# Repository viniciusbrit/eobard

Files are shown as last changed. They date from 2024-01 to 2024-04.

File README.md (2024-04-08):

# Meet Eobard, a split 34 key ortholinear keyboard.
Current Hardware Revision: 0.2.8



## Project Description
Eobard is an ortholinear 34 key split keyboard made for my personal needs. Inspired by the [Ferris](https://github.com/pierrechevalier83/ferris).

The columns are spaced out vertically so as to provide the most comfortable typing experience for my hand size. It is designed to be cheap to manufacture and simple to assemble. The single PCB is dual sided, only having to be flipped around for assembly of the other side.

<details>
<summary>Hardware Tasks</summary>

- [x] Design Layout. 
- [x] Design PCB & Plate.
- [x] Generate Gerbers.
- [x] Build Prototype.
- [ ] Write Build Guide with images.
- [x] Change 5th Column Spacing to a more comfortable distance.
- [ ] Make the right side's BOOTSEL button more accessible after soldering.
- [x] Get permission to use the BTW creature in silkscreen.
- [x] Change Placement of TRRS footprints on PCB.
- [x] Move Thumb Keys to Rows 4 and 5.
- [x] Make board diodeless.
- [ ] Release First Version.
</details>

<details>
<summary>Software Tasks</summary>

- [x] Write US English Base Layout.
- [x] Write EU Portuguese Base Layout.
</details>

## Images

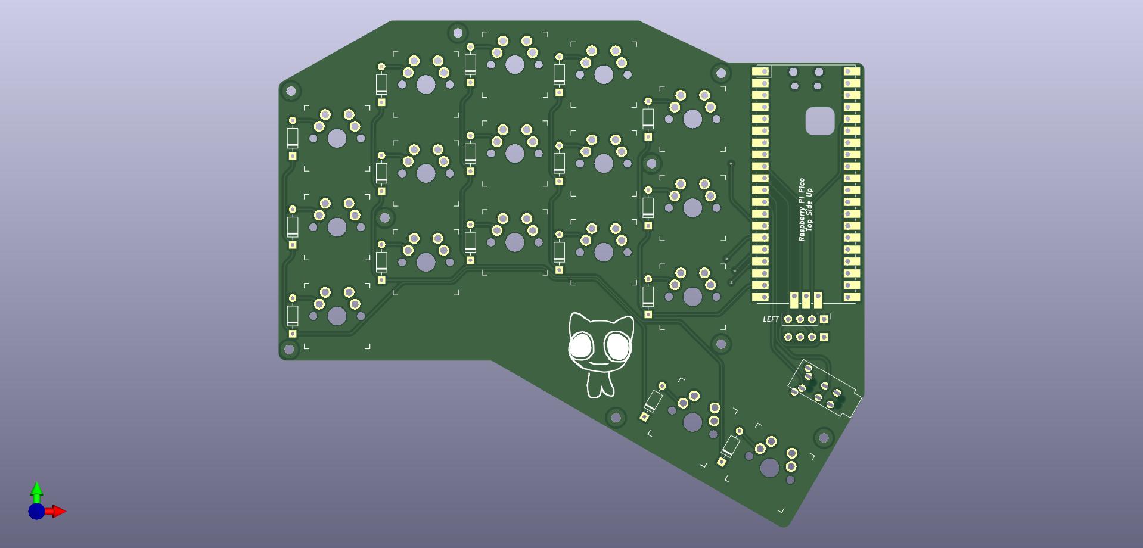
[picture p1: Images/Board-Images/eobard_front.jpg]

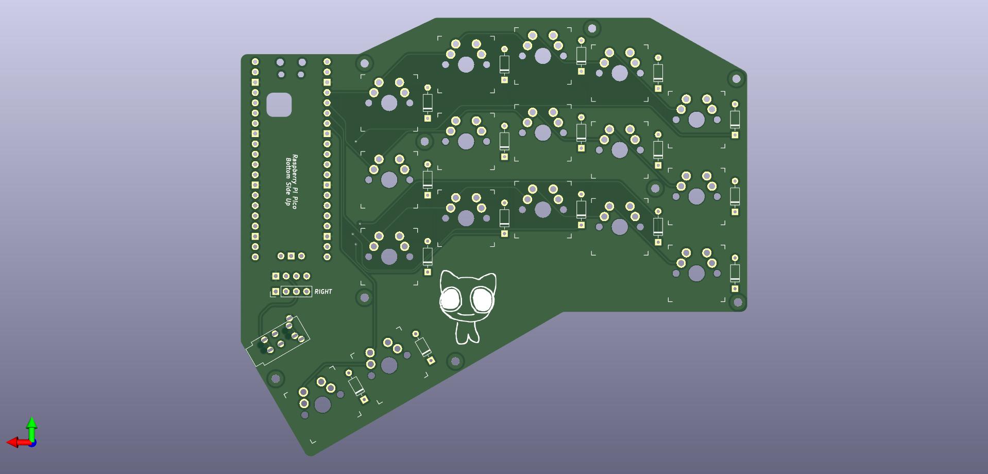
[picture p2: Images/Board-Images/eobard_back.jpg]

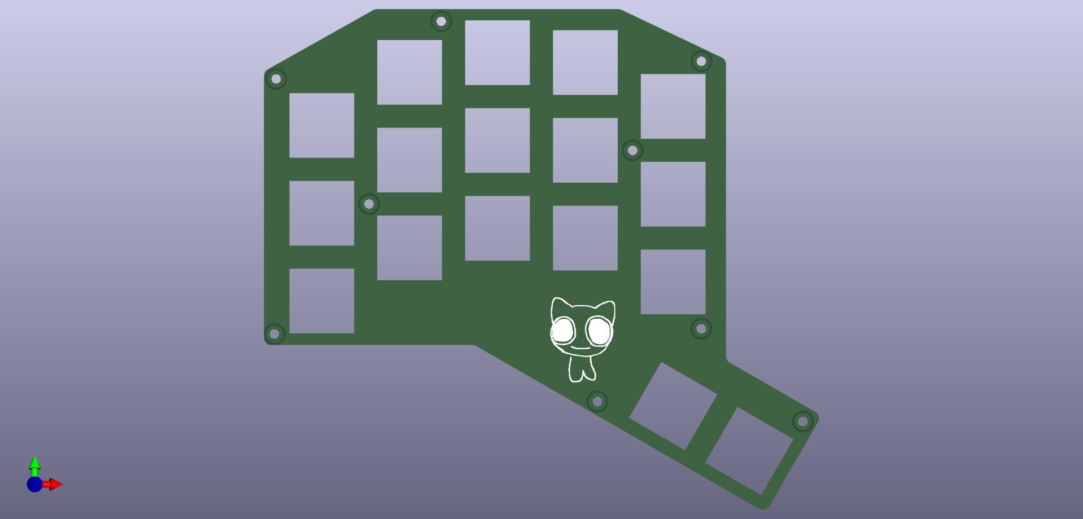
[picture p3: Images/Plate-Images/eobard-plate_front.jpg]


## Bill of materials
* Raspberry Pi Pico [x2]
* [PJ-320A 3.5mm Audio Jack [x2]](https://www.lcsc.com/product-detail/Audio-Connectors_Hong-Cheng-HC-PJ-320A_C7501806.html)
* Cherry MX Style Switches [x34]
* 4mm M2 Standoff [x9]
* 3mm M2 Screws [x18]
* 01x20 2.54mm Standard Male Pin Headers [x4] [If Pico doesn't have them pre-soldered]

## Ordering PCBs
Dragging and dropping the provided Gerber zips onto JLCPCB or other manufacturer's websites should work just fine. Make sure the plate PCB is 1mm thick and the main pcb is 1.6mm thick.

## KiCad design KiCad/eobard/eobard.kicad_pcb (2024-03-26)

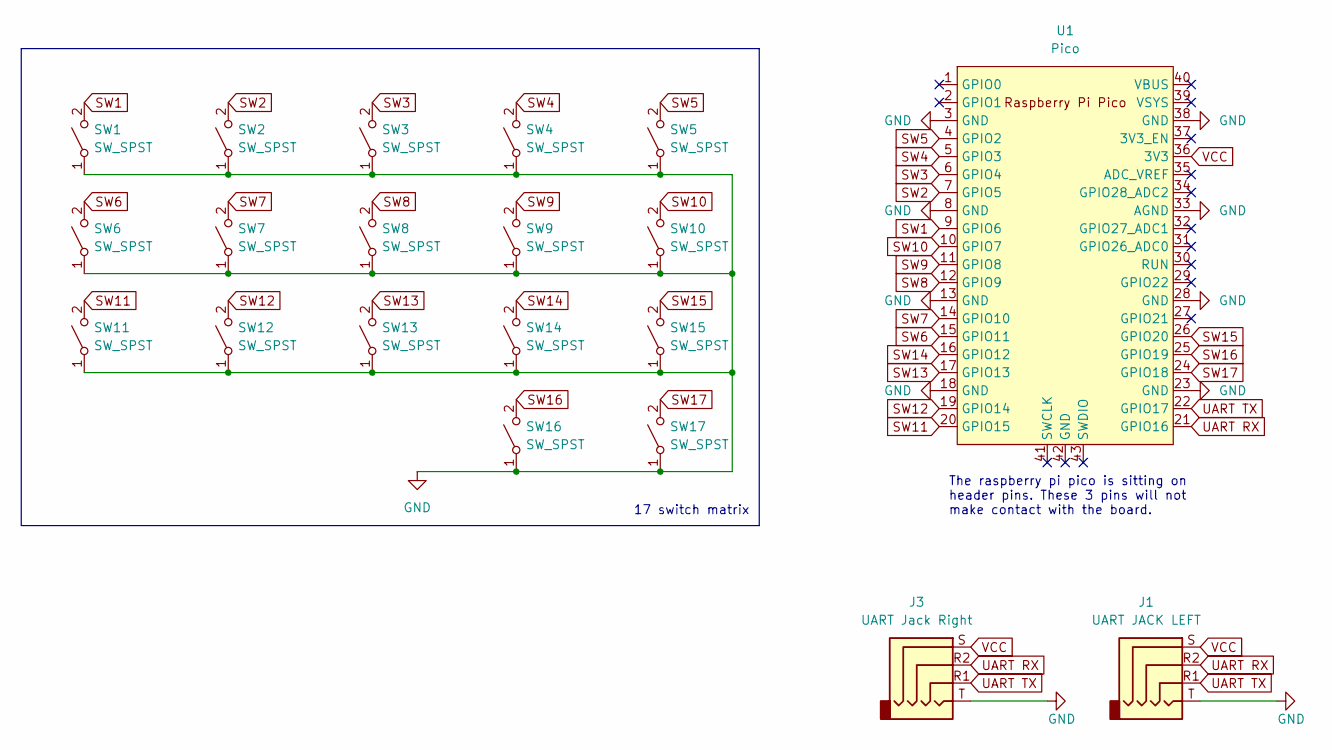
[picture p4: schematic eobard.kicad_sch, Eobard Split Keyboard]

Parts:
J1: UART JACK LEFT; PJ-320A
J3: UART Jack Right; PJ-320A
SW1, SW2, SW3, SW4, SW5, SW6, SW7, SW8, SW9, SW10, SW11, SW12, SW13, SW14, SW15, SW16, SW17: SW_SPST; SW_MX_reversible
U1: Pico; RPi_Pico_SMD_TH

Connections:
GND: J1.T, J3.T, SW1.1 (A), SW2.1 (A), SW3.1 (A), SW4.1 (A), SW5.1 (A), SW6.1 (A), SW7.1 (A), SW8.1 (A), SW9.1 (A), SW10.1 (A), SW11.1 (A), SW12.1 (A), SW13.1 (A), SW14.1 (A), SW15.1 (A), SW16.1 (A), SW17.1 (A), U1.3 (GND), U1.8 (GND), U1.13 (GND), U1.18 (GND), U1.23 (GND), U1.28 (GND), U1.33 (AGND), U1.38 (GND)
SW1: SW1.2 (B), U1.9 (GPIO6)
SW2: SW2.2 (B), U1.7 (GPIO5)
SW3: SW3.2 (B), U1.6 (GPIO4)
SW4: SW4.2 (B), U1.5 (GPIO3)
SW5: SW5.2 (B), U1.4 (GPIO2)
SW6: SW6.2 (B), U1.15 (GPIO11)
SW7: SW7.2 (B), U1.14 (GPIO10)
SW8: SW8.2 (B), U1.12 (GPIO9)
SW9: SW9.2 (B), U1.11 (GPIO8)
SW10: SW10.2 (B), U1.10 (GPIO7)
SW11: SW11.2 (B), U1.20 (GPIO15)
SW12: SW12.2 (B), U1.19 (GPIO14)
SW13: SW13.2 (B), U1.17 (GPIO13)
SW14: SW14.2 (B), U1.16 (GPIO12)
SW15: SW15.2 (B), U1.26 (GPIO20)
SW16: SW16.2 (B), U1.25 (GPIO19)
SW17: SW17.2 (B), U1.24 (GPIO18)
UART RX: J1.R2, J3.R2, U1.21 (GPIO16)
UART TX: J1.R1, J3.R1, U1.22 (GPIO17)
VCC: J1.S, J3.S, U1.36 (3V3)

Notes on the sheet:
The raspberry pi pico is sitting on header pins. These 3 pins will not make contact with the board.
17 switch matrix

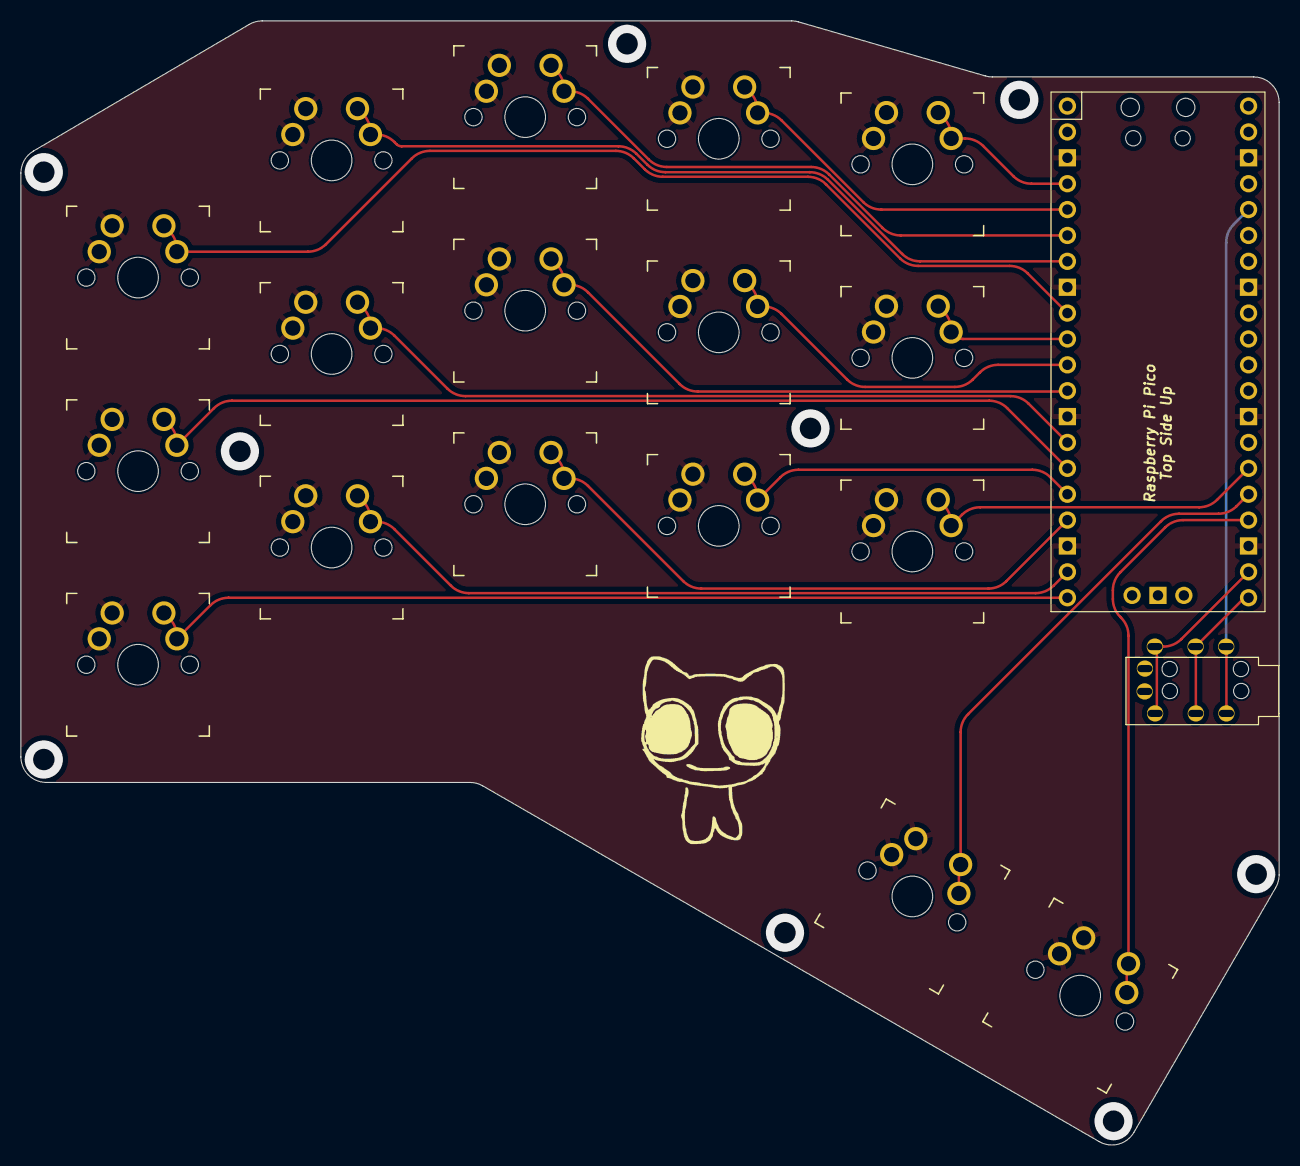
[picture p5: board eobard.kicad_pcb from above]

Board: 2 copper layers, 123.5 x 110.3 mm, 20 parts (1 on the bottom side), 21 nets.

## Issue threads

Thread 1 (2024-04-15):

Plate archive request

sukiezy, 2024-04-15:
Yo, pls could you send me the plate file?

viniciusbrit, 2024-04-15:
I think you can go back on the commits and download it from there. I'm working on a new version but my schedule sucks at the moment. If you need it though I can get the old files and stash them in a folder.

viniciusbrit, 2024-04-15:
Closed by accident

sukiezy, 2024-04-15:
> Closed by accident

> I think you can go back on the commits and download it from there. I'm working on a new version but my schedule sucks at the moment. If you need it though I can get the old files and stash them in a folder.

Ok, thanks for reply.

viniciusbrit, 2024-04-15:
I should mention that some of the imported symbols and footprints on those files were themselves github repositories that didn't get carried over into this one so you probably have to look for those too.

Closed 2024-04-15.

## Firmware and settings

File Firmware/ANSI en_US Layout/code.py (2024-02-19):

# ███████  ██████  ██████   █████  ██████  ██████      ███████ ██     ██ 
# ██      ██    ██ ██   ██ ██   ██ ██   ██ ██   ██     ██      ██     ██ 
# █████   ██    ██ ██████  ███████ ██████  ██   ██     █████   ██  █  ██ 
# ██      ██    ██ ██   ██ ██   ██ ██   ██ ██   ██     ██      ██ ███ ██ 
# ███████  ██████  ██████  ██   ██ ██   ██ ██████      ██       ███ ███  
#                         
## Written by viniciusbrit, 2024
## en_US Layout

print("Starting")
import board

from kmk.kmk_keyboard import KMKKeyboard
from kmk.keys import KC
from kmk.scanners import DiodeOrientation
from kmk.modules.split import Split, SplitType
from kmk.modules.layers import Layers

keyboard = KMKKeyboard()
keyboard.debug_enabled = True

### Keyboard Modules
split = Split(split_type=SplitType.UART, split_side=None, data_pin=board.GP9, data_pin2=board.GP8, uart_flip=True, use_pio=True)
keyboard.modules.append(split)
layers = Layers()
keyboard.modules.append(layers)

### Key Matrix and Diodes
keyboard.col_pins = (board.GP10,board.GP11,board.GP12,board.GP13,board.GP14) 
keyboard.row_pins = (board.GP2,board.GP3,board.GP4,board.GP5)
keyboard.diode_orientation = DiodeOrientation.ROW2COL

### Cleanup naming scheme
_______ = KC.TRNS
XXXXXXX = KC.NO

### Home Row Layer Taps
S_L2 = KC.LT(2, KC.S)
D_L1 = KC.LT(1, KC.D)
F_L4 = KC.LT(4, KC.F)
J_L3 = KC.LT(3, KC.J)
K_L5 = KC.LT(5, KC.K)
SPC_L6 = KC.LT(6, KC.SPC)

### Keymap
keyboard.keymap = [
    [  # 0 QWERTY LAYER
        KC.Q,    KC.W,    KC.E,    KC.R,    KC.T,    KC.Y,    KC.U,    KC.I,    KC.O,    KC.P,
        KC.A,    S_L2,    D_L1,    F_L4,    KC.G,    KC.H,    J_L3,    K_L5,    KC.L, KC.SCLN,
        KC.Z,    KC.X,    KC.C,    KC.V,    KC.B,    KC.N,    KC.M, KC.COMM,  KC.DOT, KC.SLSH,
     KC.LSFT,  SPC_L6, XXXXXXX, XXXXXXX, XXXXXXX, XXXXXXX, XXXXXXX, XXXXXXX,  KC.ENT, KC.BSPC,
    ],
    [  # 1 NAVIGATION LAYER
    _______, _______, _______, _______, _______, _______, _______, KC.PGUP, _______, _______,
    KC.PSCR, KC.LGUI, _______, KC.HYPR, _______, KC.LEFT, KC.DOWN,   KC.UP, KC.RGHT, _______,
    _______, _______, _______, _______, _______, _______, KC.HOME, KC.PGDN,  KC.END, _______,
    _______, _______, _______, _______, _______, _______, _______, _______, _______, _______,
    ],
    [  # 2 NUMPAD
    _______, _______, _______, _______, _______, KC.SLSH,   KC.N7,   KC.N8,   KC.N9, KC.MINS,
    _______, _______, _______, _______, _______, KC.ASTR,   KC.N4,   KC.N5,   KC.N6, KC.PLUS,
    _______, _______, _______, _______, _______,   KC.N0,   KC.N1,   KC.N2,   KC.N3,  KC.EQL,
    _______, _______, _______, _______, _______, _______, _______, _______, _______, _______,
    ],
    [  # 3 LEFT SYMBOLS
    _______, KC.COLN, KC.LABK, KC.RABK, KC.SCLN, _______, _______, _______, _______, _______,
    KC.LCBR, KC.RCBR, KC.LPRN, KC.RPRN,   KC.AT, _______, _______,  KC.EQL, KC.PLUS, KC.PERC,
    _______, KC.EXLM, KC.LBRC, KC.RBRC, _______, _______, _______, _______, _______, _______,
    _______, _______, _______, _______, _______, _______, _______, _______, _______, _______,
    ],
    [  # 4 RIGHT SYMBOLS
    _______, _______, _______, _______, _______, _______, KC.UNDS, KC.PIPE, KC.QUOT, _______,
    KC.CIRC, KC.ASTR, KC.AMPR, _______, _______, KC.HASH, KC.TILD, KC.SLSH, KC.DQUO,  KC.DLR,
    _______, _______, _______, _______, _______, _______, KC.MINS, KC.BSLS,  KC.GRV, _______,
    _______, _______, _______, _______, _______, _______, _______, _______, _______, _______,
    ],
    [  # 5 FUNCTION KEYS
      KC.F9,  KC.F10,  KC.F11,  KC.F12, _______, _______, _______, _______, _______, _______,
      KC.F5,   KC.F6,   KC.F7,   KC.F8, _______, _______, _______, _______, _______, _______,
      KC.F1,   KC.F2,   KC.F3,   KC.F4, _______, _______, _______, _______, _______, _______,
    _______, _______, _______, _______, _______, _______, _______, _______, _______, _______,
    ],
    [  # 6 ALWAYS AVAILABLE [THUMB QUICK ACCESS LAYER]
    _______, _______, KC.COLN,  KC.ESC, _______, _______, _______, _______, _______,  KC.DEL,
     KC.TAB, KC.PERC, KC.SLSH,  KC.ENT, _______, _______, KC.LGUI, _______, _______, _______,
    KC.CAPS, _______, _______, KC.PERC, _______, _______, KC.RALT, KC.RCTL, _______, KC.RESET,
    _______, _______, _______, _______, _______, _______, _______, _______, _______, _______,
    ],
]

if __name__ == '__main__':
    keyboard.go()

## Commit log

2024-01-08 Added README & KiCad Files
    [eobard-B_Cu.gbl, eobard-B_Mask.gbs, eobard-B_Paste.gbp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]
2024-01-08 Updated KiCad Files
    [eobard.kicad_pcb]
2024-01-08 Updated Plate Mounting Holes
    [eobard-plate.kicad_pcb]
2024-01-12 Fixed Silkscreen Error & Changed Mounting Hole Position
    [eobard-B_Cu.gbl, eobard-B_Mask.gbs, eobard-B_Paste.gbp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]
2024-01-12 Fixed Footprint Error
    [eobard-B_Cu.gbl, eobard-B_Mask.gbs, eobard-B_Paste.gbp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]
2024-01-12 Removed Old Plate, Slight PCB Changes
    [eobard-B_Cu.gbl, eobard-B_Mask.gbs, eobard-B_Paste.gbp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]
2024-01-12 Updated PCB Gerbers
    [eobard-B_Cu.gbl, eobard-B_Mask.gbs, eobard-B_Paste.gbp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]
2024-01-12 Updated Board Design
    [eobard-B_Cu.gbl, eobard-B_Mask.gbs, eobard-B_Paste.gbp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]
2024-01-12 Added New Plate Design
    [eobard-plate-B_Cu.gbl, eobard-plate-B_Mask.gbs, eobard-plate-B_Paste.gbp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]
2024-02-17 Fixed A Single Key
    [code.py]
2024-02-18 Reorganized Project Files
    [eobard-B_Cu.gbl, eobard-B_Mask.gbs, eobard-B_Paste.gbp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]
2024-02-18 Updated Layouts
    Added Print Screen
2024-03-25 Updated Project
    Started work on version 1.0.
    Dealing with a few bugs on KiCad right now...
    Reorganized file structure
    [eobard-plate-B_Cu.gbl, eobard-plate-B_Mask.gbs, eobard-plate-B_Paste.gbp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]
2024-03-26 Finished Initial Board Layout
    Improving on the prototype. Gerbers are inside kicad folder.
    [eobard-B_Cu.gbl, eobard-B_Mask.gbs, eobard-B_Paste.gbp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]
2024-03-26 Tiny Layout Change
    [eobard-B_Cu.gbl, eobard-B_Mask.gbs, eobard-B_Paste.gbp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]
2024-03-26 Updated BOM
    Bill of materials has been updated to reflect new design requirements.
